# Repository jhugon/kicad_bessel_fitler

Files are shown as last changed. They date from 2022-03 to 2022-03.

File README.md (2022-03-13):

# LC Bessel Filter in KiCAD

3th order Pi filter with 50 ohm in/out impedance

E24 series caps seems available as 1% 1206.

Coilcraft makes variable inductors and fixed 1206CS series in E12 values.

From SPICE studies on 10 MHz, it seems that even 5% values for all components
will be fine. There is already a bit of ripple at the end of the impulse
response, and the component variation is smaller than the ripple.

I'm going to make a main branch with a variable inductor as well as another
branch with a 1206CS fixed inductor.

## For 6 MHz

27 ns time const and 58 ns rise time

- L1 = 1u287
- C1 = 179p
- C2 = 1n169

Parts:

- L1 = 143-18J12L (unshielded over 1 uH)
- C1 = 180p
- C2 = 1200p

## 10 MHz

16 ns time const and 35 ns rise time.

- L1 = 772n3
- C1 = 107p4
- C2 = 701p4

Parts:

- L1 = 143-17J12SL
- C1 = 110p
- C2 = 680p

## 20 MHz

8 ns time const and 16 ns rise time

- L1 = 386n2
- C1 = 53p70
- C2 = 350p7

Parts:

- L1 = 143-09J12SL
- C1 = 56p
- C2 = 360p

## 40 MHz

4 ns time const and 8.8 ns rise time

- L1 = 193n1
- C1 = 26p85
- C2 = 175p3

Parts:

- L1 = 144-07J12SL
- C1 = 27p
- C2 = 180p

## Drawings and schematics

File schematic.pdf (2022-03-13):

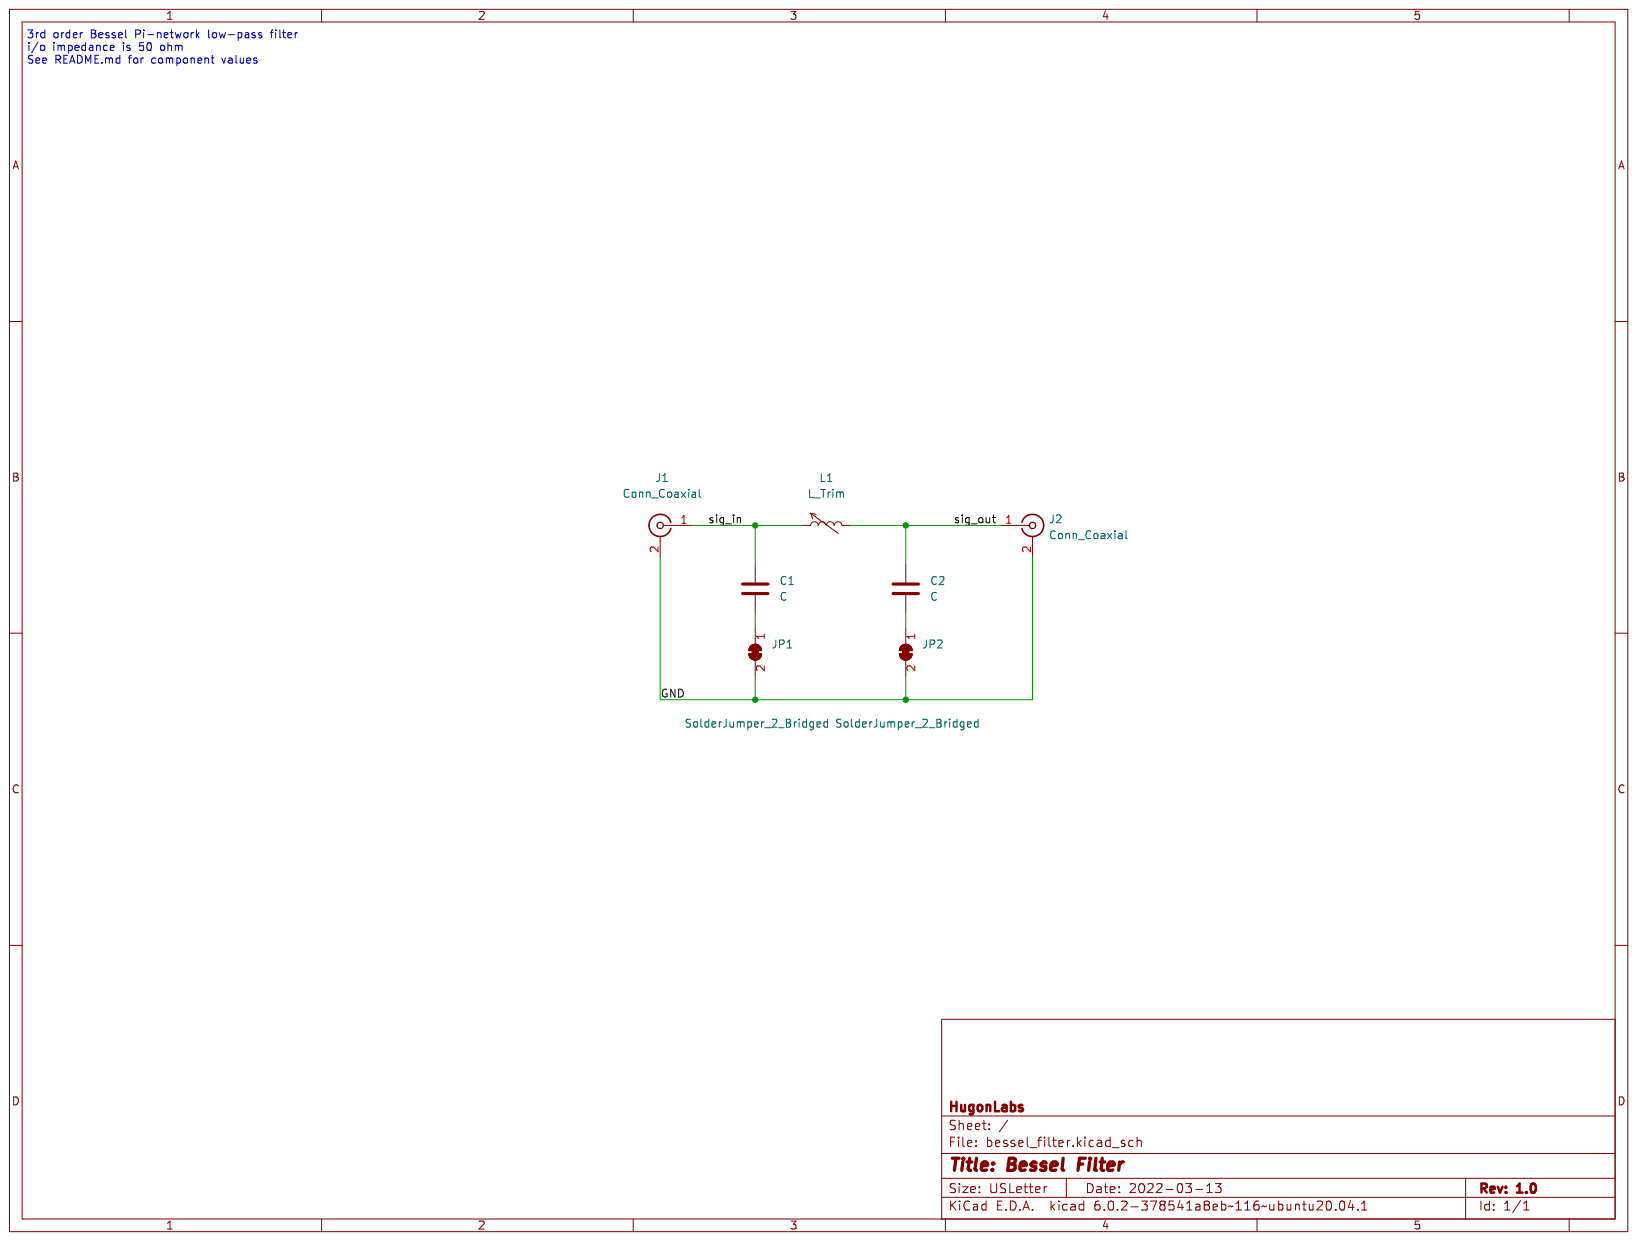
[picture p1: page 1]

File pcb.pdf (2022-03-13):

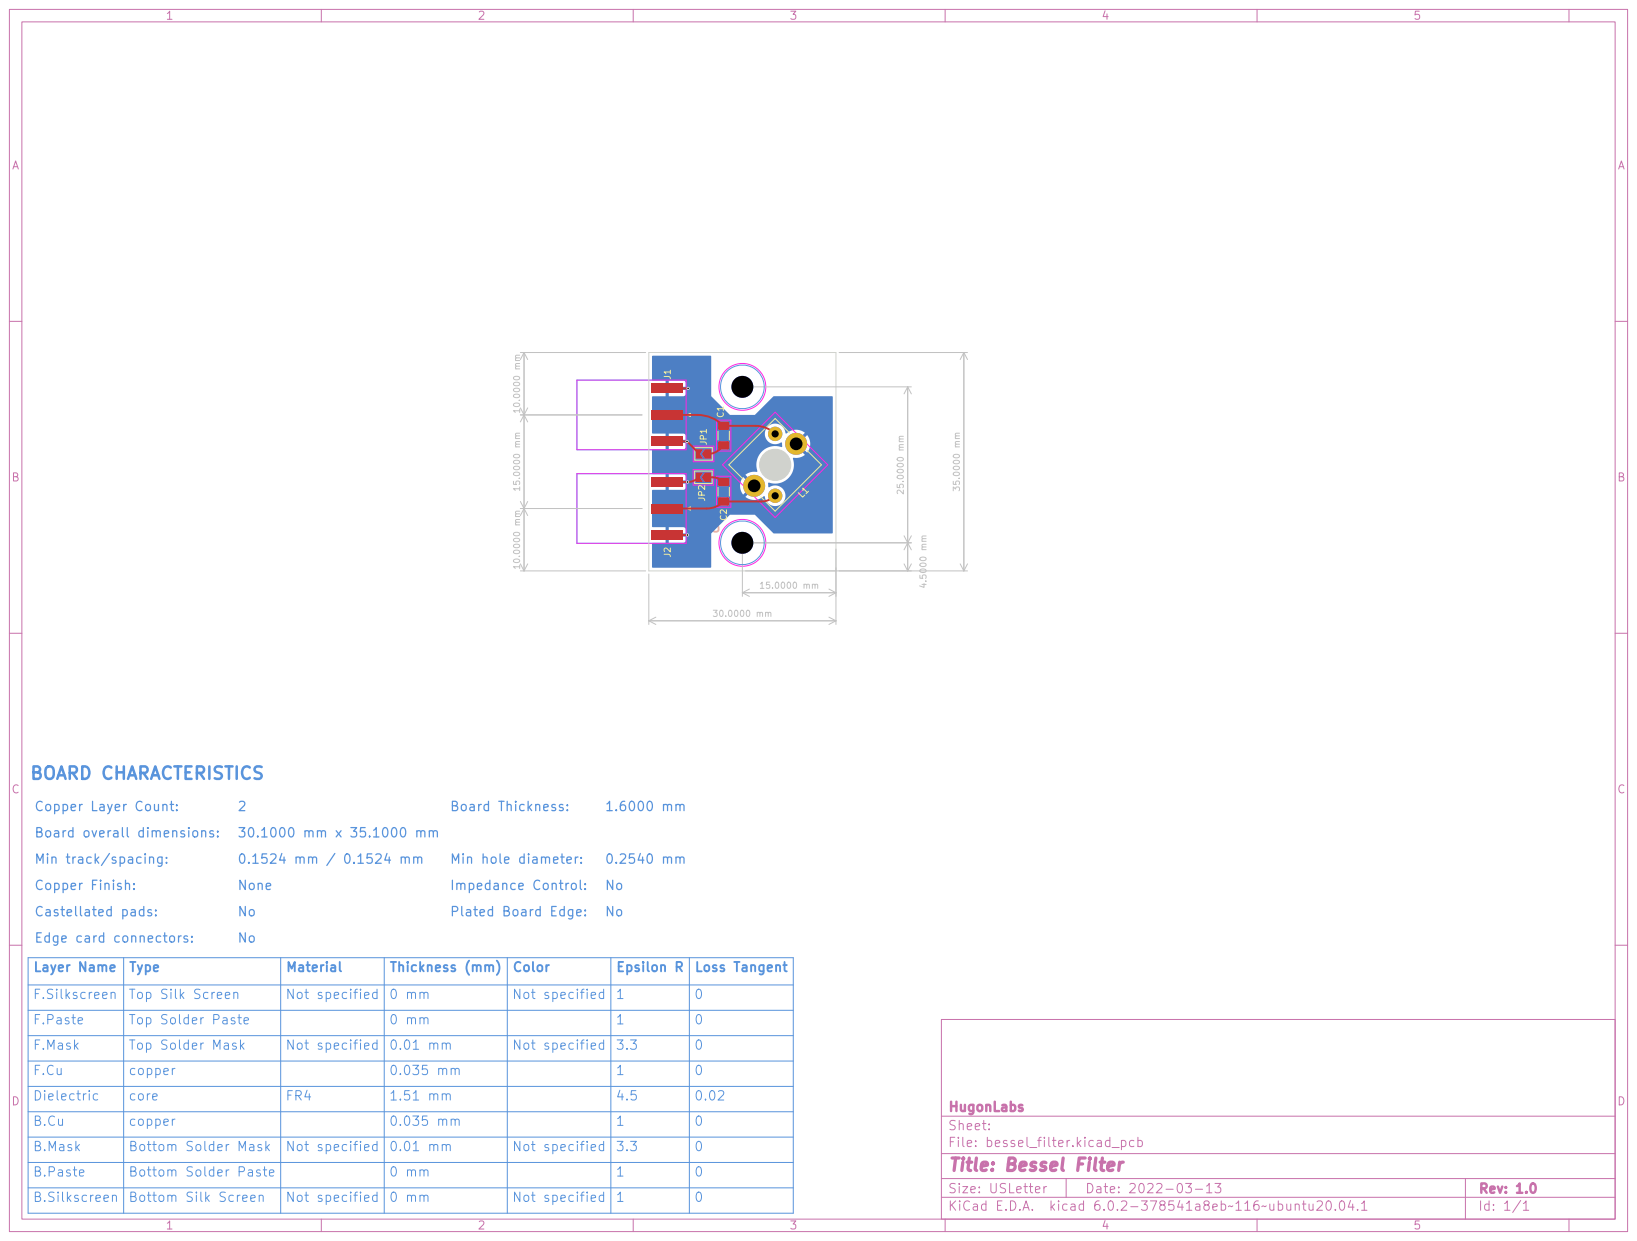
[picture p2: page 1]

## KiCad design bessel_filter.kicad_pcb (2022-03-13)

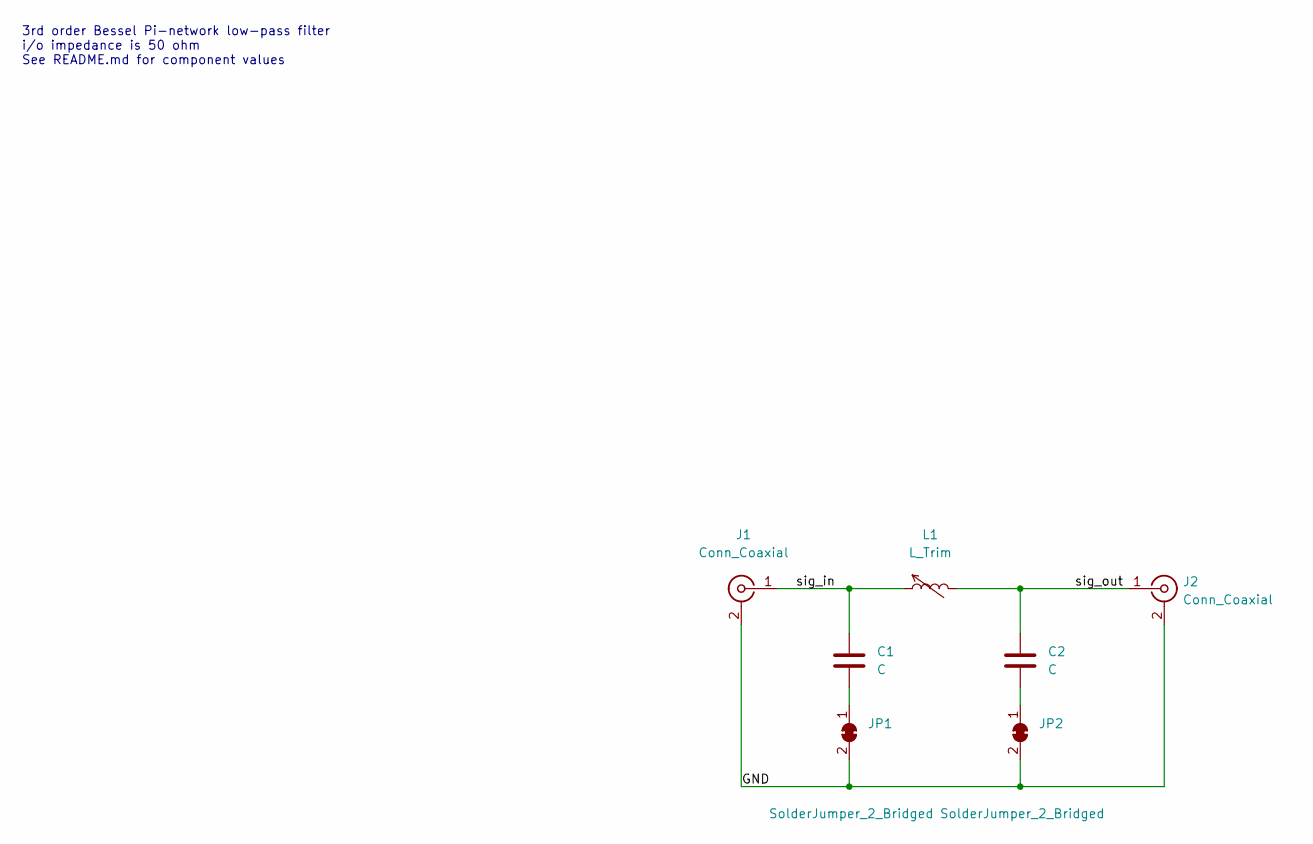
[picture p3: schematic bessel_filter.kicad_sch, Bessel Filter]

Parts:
C1, C2: C; C_1206_3216Metric_Pad1.33x1.80mm_HandSolder
J1, J2: Conn_Coaxial; SMA_Amphenol_132289_EdgeMount
JP1, JP2: SolderJumper_2_Bridged; SolderJumper-2_P1.3mm_Open_TrianglePad1.0x1.5mm
L1: L_Trim; Coil_Craft_Unicoil_10mm

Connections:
/GND: J1.2 (Ext), J2.2 (Ext), JP1.2 (B), JP2.2 (B), L1.GND
/sig_in: C1.1, J1.1 (In), L1.1
/sig_out: C2.1, J2.1 (In), L1.2
unnamed: C1.2, JP1.1 (A)
unnamed: C2.2, JP2.1 (A)

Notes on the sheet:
3rd order Bessel Pi-network low-pass filter i/o impedance is 50 ohm See README.md for component values

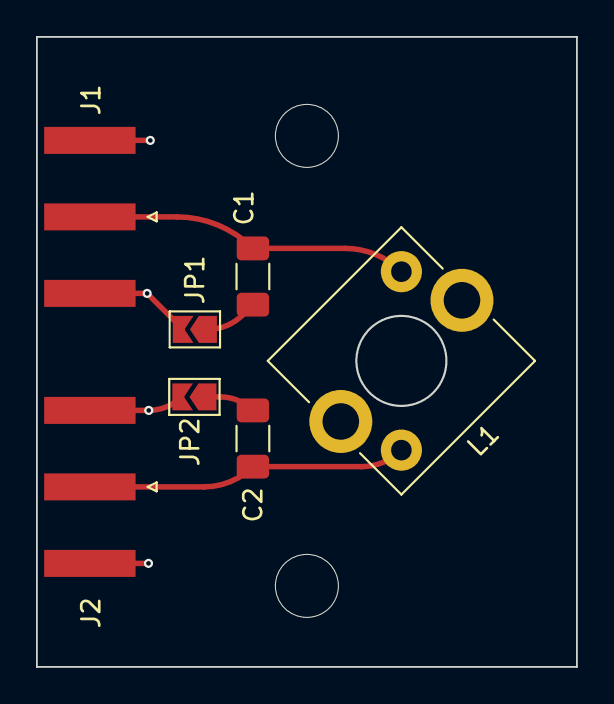
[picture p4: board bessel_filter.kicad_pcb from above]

Board: 2 copper layers, 30.0 x 35.0 mm, 7 parts (0 on the bottom side), 5 nets.

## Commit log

2022-03-10 added scaled L/C values
    [bessel_filter.kicad_sch]
2022-03-12 Added README
    with info
    fixed L1 value in schematic
    [bessel_filter.kicad_sch]
2022-03-12 switched to 3rd order filter for simplicity
    component values are moved from schematic to README.md
    [bessel_filter.kicad_sch]
2022-03-12 Added filter_response.py and spice submodule
    and spice_template.cir
2022-03-13 filter_response.py: variational analysis on component vals
2022-03-13 progress on PCB--need to add L shield to ground connections
    [bessel_filter.kicad_pcb, bessel_filter.kicad_sch]
2022-03-13 PCB finished
    [bessel_filter.kicad_pcb, bessel_filter.kicad_sch]
2022-03-13 Added gerbers
    [bessel_filter-B_Cu.gbl, bessel_filter-B_Mask.gbs, bessel_filter-B_Paste.gbp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]
